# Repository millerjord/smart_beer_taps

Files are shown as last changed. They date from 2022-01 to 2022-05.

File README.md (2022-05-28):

# Smart Beer Taps
ESP based smart beer taps with eInk screens

## Background
I am a homebrewer, and a home automation enthusiast.

I use kegs for serving my beers, since I don't fancy filling bottles with all that hassle. I have a tap tower, with three taps. Then I wanted to know how much beer is left in the kegs, as well as what beer is in what tap. That started my project.

The final goal is to have the setup in a keezer, in my outdoor kitchen. Until then, it is temporary setups to make this work. 

For measuring the content of the kegs I did find the following project, that includes all you need to buy, STL files for 3D printing the base and the code to both run and calibrate the scale.

https://github.com/Callwater/Beerkeg-load-cell

Since I will use a keezer, and will have (at least) 3 kegs in there, I do not have the DHT22 sensors in my setup. I will rather use an InkBird ITC-308 with wifi to measure that.

Then for the taphandles, I decided I wanted to use an eInk display to dynamically show what beers are in the kegs and how much is left. I did find some TTGO T5 with a 2.13 inch eInk display included that works perfectly for me. I bought them off Amazon.

The reason for the eInk display is that it will show data even if the device is not powered up. I don't drink beer 24/7, so that makes it possible for me to only update the display during certain times of the week. And then I can run on battery for quite a long time.

At home I run Home Assistant for all my home automation. So I have quite a lot of data there, and hence decided to utilize ESPhome in the taphandles. The information about the beers, like ABV, IBU and EBC I do have in a local database, and I have a SQL server sensor in HA that pulls that data in. The scales under the kegs send data via MQTT to Home Assistant. So I have all necessary information in there, which makes it pretty easy to display what is needed.

On the display I am also printing a QR code to Untappd, where I have more information about the beer and I give my friends coming over a chance to rate the beers. Quite fun really. As of a few months ago there is a module to create the QR code within ESPHome. It took me some months to figure out how to use that, since it is not templateable. Got some help on the community forums, and now it is working!

And for the taphandles I did find some STL's at Thingiverse, I have even added them to this repo for simplicity. 
https://www.thingiverse.com/thing:4891896

## How-to

First of all you will need to 3D print the taphandles. I did scale them to 101%, and then they were easier to fit on the tap, didn't have to re-thread the handle.

You will also need the ESP32 with the eInk screen, and it needs to be the 2.13" or you will have to change the output to fit the screen.

For the untappd QR code I have put the entire link in the database about the beer, and read that into the code. 

(When browsing to untappd and selecting a beer, you will see a unique number in the URL. That number is what I have used here.)

You will also need to have installed the ESPhome CLI. You do that by using this command

```
pip3 install esphome
```

Also, in the top of the tap1.yaml file you will find a list of substitutions. Change these to reflect your environment.

Then you will have to create your own secret.yaml-file. This file should contain the following information:

```
wifi_ssid: {your wifi name here}
wifi_password: {your wifi PSK here}
fallback_password: {fallback password for the ESP}
esphome_api_password: {API password for connection with HA}
```

And finally you just run the code to compile it, and store it to the ESP32 (that you have connected via USB to your computer)

```
esphome run tap1.yaml
```

## Still to do

I have to find a smart way to wrap the name of the beer over two lines.

## Images of the taps, as of May 28th 2022

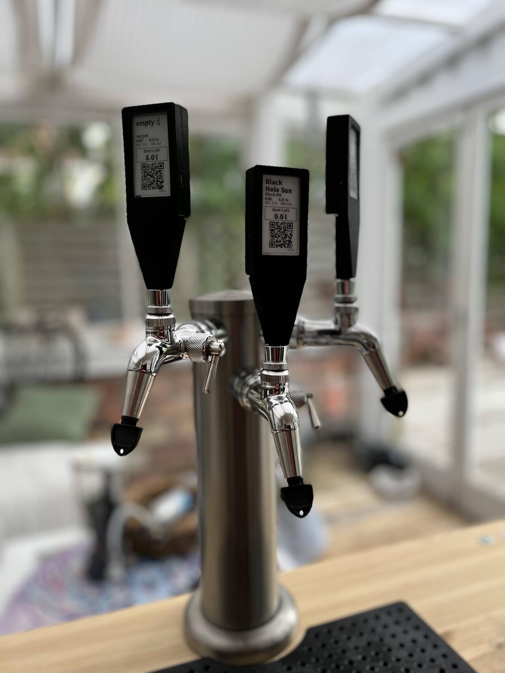
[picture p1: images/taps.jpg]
Picture of all the taps in the tower


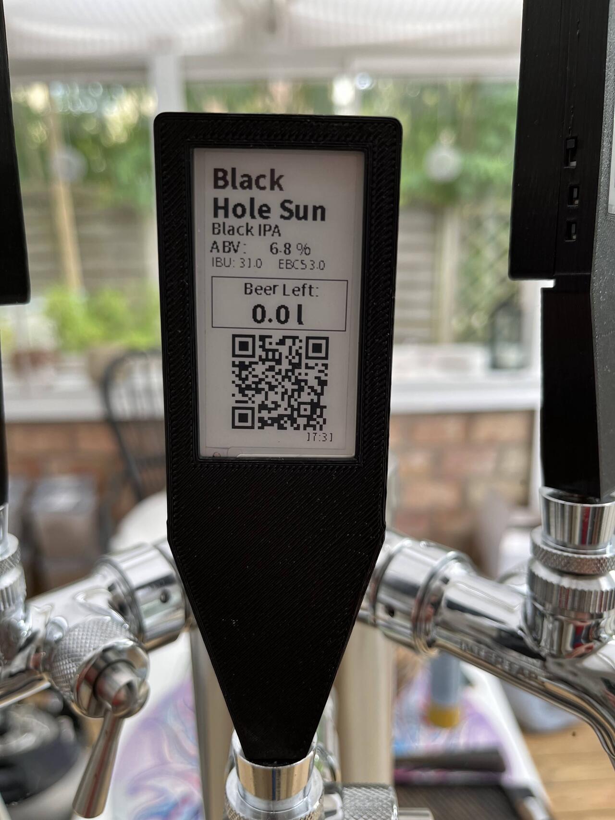
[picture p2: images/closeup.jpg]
Closeup picture of the display in one of the taps


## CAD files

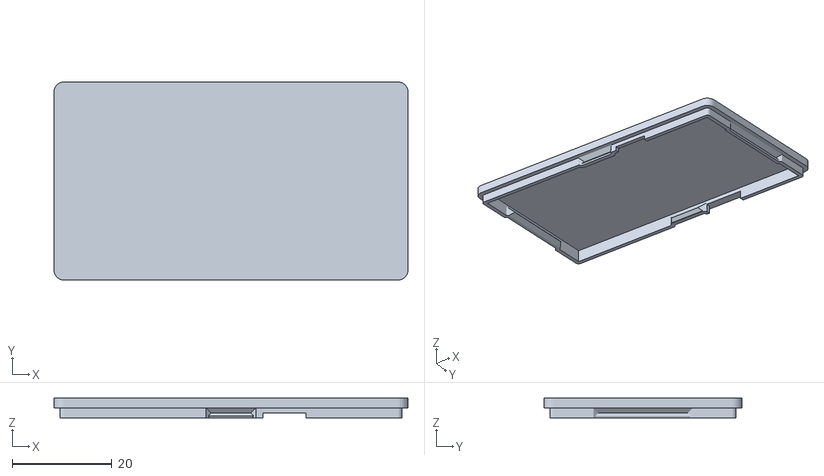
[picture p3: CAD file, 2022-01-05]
stl/TTGO_T5_Enclosure_-_Lid.stl
71.0 x 39.8 x 4.00

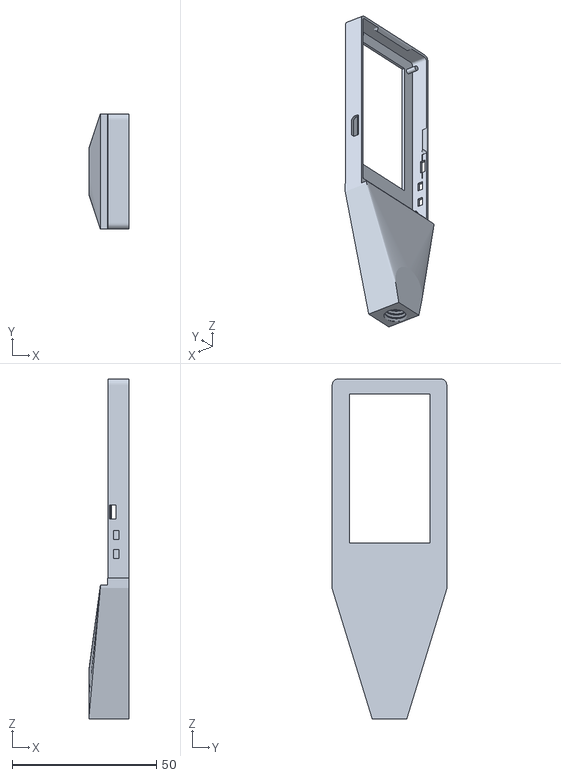
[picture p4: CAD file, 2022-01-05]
stl/taphandle-v2.stl
14.0 x 40.0 x 118.0

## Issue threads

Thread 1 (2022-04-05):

Battery Suggestion

mcgeebc, 2022-04-05:
This is a great project. Thanks for making it available! I have it working on one of my taps now and am working to expand to all five.

I'm wondering if you have a suggestion on a battery that works with the board and fits in the case?

Thanks again!!

millerjord, 2022-05-28:
Sorry for a really late reply, I have not gotten any notification for this.

I have bought some 1100 mAh batteries off Amazon, a 4 pack for just over €30.

The size of the batteries:  LxWxH | 45 x 25 x 10 millimeters

This is the link to the batteries off Amazon, there are probably many similar options

https://www.amazon.se/gp/product/B087LTZW61/ref=ppx_yo_dt_b_asin_title_o02_s02?ie=UTF8&th=1&language=en_GB

mcgeebc, 2022-09-10:
@millerjord  Sorry. Me again. I noticed your pictures look like you extended the back to fit the battery. Can you share the updated STL? It's working great for me, but I'm still plugging them in to update. Thanks again!!

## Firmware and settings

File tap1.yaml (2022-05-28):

substitutions: #substitute your own values in this section
  device_name: tap1
  device_name_status: "Tap 1 Status"
  device_name_battery: "Tap 1 battery"
  device_description: "ePaper display for Taphandle number 1"
  beer_name: sensor.keg_1_beer #entity from Home Assistant
  beer_style: sensor.keg_1_style #entity from Home Assistant
  beer_abv: sensor.keg_1_abv #entity from Home Assistant
  beer_ebc: sensor.keg_1_ebc #entity from Home Assistant
  beer_ibu: sensor.keg_1_ibu #entity from Home Assistant
  beer_brewdate: sensor.keg_1_brewdate #entity from Home Assistant
  beer_left: sensor.keg_1_weight #entity from Home Assistant
  untappd : sensor.tap_1_untappd #entity from Home Assistant

#---------------------------------------------------------------------------------------------

globals:
  - id: valueCount
    type: int
    restore_value: no
    initial_value: "0"

esphome:
  name: '${device_name}'
  comment: '${device_description}'
  platform: ESP32
  board: esp32dev
  on_boot:
    priority: -100
    then:
      - logger.log: "boot ready..."
      - wait_until: 
          - lambda: |- 
              auto time = id(sntp_time).now();
              return (time.is_valid());
# Removed due to impressively bad batterytime
#      - if:
#          condition:
#            - lambda: 'return ((id(sntp_time).now().hour < 22) || (id(sntp_time).now().hour > 6)) ;' # adjust sleep time to hour of the day
#          then:
#            - logger.log: "daytime..."
#            - lambda: 'id(deep_sleep_1).set_sleep_duration(60*1000);'
#          else:
#            - logger.log: "nighttime..."
#            - lambda: 'id(deep_sleep_1).set_sleep_duration(30*60*1000);'
  on_loop:
    then:
      - if:
          condition:
            lambda: 'return (id(valueCount) == 8) ;'  # Number of sensors to grab values from
          then:
            - logger.log: "all values ready..."
            - component.update: my_display
            - if:
                condition:
                  binary_sensor.is_off: prevent_deep_sleep
                then:
                  - deep_sleep.enter: deep_sleep_1
                else:
                  - logger.log: "Skipping deep sleep"

          else:
            # - logger.log: "waiting for values..."
            

wifi:
  ssid: !secret wifi_ssid
  password: !secret wifi_password
  fast_connect: on #Do not scan for networks  

# Enable logging
logger:

# Enable Home Assistant API
api:
  password: !secret esphome_api_password

ota:
  safe_mode: true
  reboot_timeout: 10min
  num_attempts: 5

time:
  - platform: sntp
    id: sntp_time
  

binary_sensor:
  - platform: status
    name: '${device_name_status}'
 
  - platform: homeassistant
    id: prevent_deep_sleep
    name: Prevent Deep Sleep
    entity_id: input_boolean.prevent_deep_sleep


deep_sleep:
  id: deep_sleep_1
  sleep_duration: 86400s  # Update automatically every 24h, otherwise press reset button
  run_duration: 30s

sensor:

  - platform: homeassistant
    id: beer_abv
    entity_id: $beer_abv
    unit_of_measurement: "%"
    internal: true
    on_value:
      then:
        - lambda: 'id(valueCount) += 1; ESP_LOGD("main", "Value %i received" , id(valueCount));'

  - platform: homeassistant
    id: beer_ebc
    entity_id: $beer_ebc
    internal: true
    on_value:
      then:
        - lambda: 'id(valueCount) += 1; ESP_LOGD("main", "Value %i received" , id(valueCount));'

  - platform: homeassistant
    id: beer_ibu
    entity_id: $beer_ibu
    internal: true
    on_value:
      then:
        - lambda: 'id(valueCount) += 1; ESP_LOGD("main", "Value %i received" , id(valueCount));'
    
  - platform: homeassistant
    id: beer_left
    entity_id: $beer_left
    internal: true
    on_value:
      then:
        - lambda: 'id(valueCount) += 1; ESP_LOGD("main", "Value %i received" , id(valueCount));'

  - platform: adc
    pin: 35
    id: "tap1_battery"
    name: '${device_name_battery}'
    attenuation: 11db

text_sensor:
  - platform: homeassistant
    id: beer_name
    entity_id: $beer_name
    internal: true
    on_value:
      then:
        - lambda: 'id(valueCount) += 1; ESP_LOGD("main", "Value %i received" , id(valueCount));'

  - platform: homeassistant
    id: beer_style
    entity_id: $beer_style
    internal: true
    on_value:
      then:
        - lambda: 'id(valueCount) += 1; ESP_LOGD("main", "Value %i received" , id(valueCount));'

  - platform: homeassistant
    id: beer_untappd
    entity_id: $untappd
    internal: true
    on_value:
      then:
        - lambda: 'id(valueCount) += 1; ESP_LOGD("main", "Value %i received" , id(valueCount));'

  - platform: homeassistant
    id: beer_brewdate
    entity_id: $beer_brewdate
    internal: true
    on_value:
      then:
        - lambda: 'id(valueCount) += 1; ESP_LOGD("main", "Value %i received" , id(valueCount));'

qr_code:
  - id: untappd_qr
    value: beer_untappd
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
